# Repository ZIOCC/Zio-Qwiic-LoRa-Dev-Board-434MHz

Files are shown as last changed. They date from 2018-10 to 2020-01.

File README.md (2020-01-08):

# Zio Qwiic LoRa Dev Board 443MHz

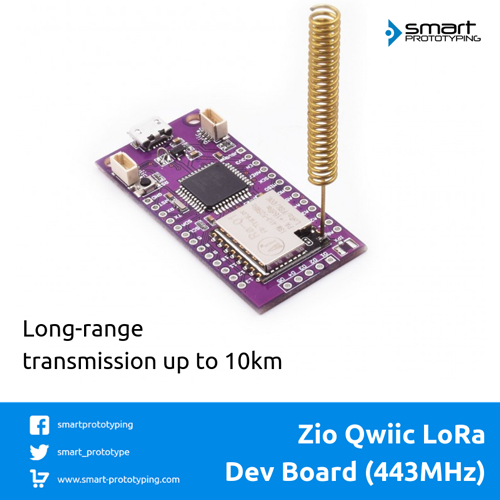
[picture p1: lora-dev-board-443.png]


> This product can be available for purchase [here](https://www.smart-prototyping.com/Zio-Qwiic-LoRa-Dev-Board-443MHz).

#### Description

We know how complicated it is to connect LoRa module, so we make your ‘connecting’ life easier. We created an Arduino IDE compatible board which combines LoRa module + ATMEGA32U4-AU. Simply use two boards, one as a transmitter and another one as a receiver, and the LoRa setup is complete!

There are two Qwiic connectors on board, so you can add more Qwiic modules within seconds without soldering and jumper wire connection. 

The Main IC ATMEGA32U4-AU has almost the same performance as ATmega328, with built-in USB so not only does it have a USB-to-Serial program and debug capability built in with no need for an FTDI-like chip, it can also act like a mouse, keyboard, USB MIDI device, etc.
You can download the driver for ATMEGA32U4-AU [here](https://github.com/adafruit/Adafruit_Windows_Drivers/releases/download/1.2/adafruit_drivers.exe). Alternatively, you can check out the installation guide [here](https://learn.adafruit.com/adafruit-arduino-ide-setup/windows-driver-installation).

The LoRa module on board is based on SX1278 and works on a 433MHz frequency. It can work as master model or slave model. With a spring antenna, the communication distance can reach up to 10 KM in open field. It is a perfect solution for building projects that need to cross a big area. We offer two kinds of LoRa modules on board (optional), the Ra-01 with spring antenna and Ra-02 with IPX antenna. 

The onboard antenna is good enough for you to test function, if you need to implement it for real projects, please solder the antenna to get the best spreading distance.

> If you are looking for the Lora Module instead, you can find it [here](https://www.smart-prototyping.com/index.php?route=product/search&search=lora)

#### Specification

* Program Memory Size (KB): 32
* CPU Speed (MIPS/DMIPS): 16
* SRAM Bytes: 2,560
* Data EEPROM/HEF (bytes): 1024
* Wireless Standard: 433MHz
* Frequency range: 420 - 450MHz

#### Links

* [PCB source file and Gerber file](https://github.com/ZIOCC/Zio-Qwiic-LoRa-Dev-Board-434MHz)
* [Demo code](https://github.com/ZIOCC/Zio-Qwiic-LoRa-Dev-Board-434MHz/tree/master/arduino-LoRa-master)
* [ATMEGA32U4-AU datasheet](http://ww1.microchip.com/downloads/en/DeviceDoc/Atmel-7766-8-bit-AVR-ATmega16U4-32U4_Datasheet.pdf)
* [Arduino IDE Bootloader](https://github.com/adafruit/Adafruit_Windows_Drivers/releases/download/1.2/adafruit_drivers.exe)

###### About Zio
> Zio is a new line of open sourced, compact, and grid layout boards, fully integrated for Arduino and Qwiic ecosystem. Designed ideally for wearables, robotics, small-space limitations or other on the go projects. Check out other awesome Zio products [here](https://www.smart-prototyping.com/Zio).

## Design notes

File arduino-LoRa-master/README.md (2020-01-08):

# Arduino LoRa



An [Arduino](https://arduino.cc/) library for sending and receiving data using [LoRa](https://www.lora-alliance.org/) radios.

## Compatible Hardware

 * [Semtech SX1276/77/78/79](http://www.semtech.com/apps/product.php?pn=SX1276) based boards including:
   * [Dragino Lora Shield](http://www.dragino.com/products/module/item/102-lora-shield.html)
   * [HopeRF](http://www.hoperf.com/rf_transceiver/lora/) [RFM95W](http://www.hoperf.com/rf_transceiver/lora/RFM95W.html), [RFM96W](http://www.hoperf.com/rf_transceiver/lora/RFM96W.html), and [RFM98W](http://www.hoperf.com/rf_transceiver/lora/RFM98W.html)
   * [Modtronix](http://modtronix.com/) [inAir4](http://modtronix.com/inair4.html), [inAir9](http://modtronix.com/inair9.html), and [inAir9B](http://modtronix.com/inair9b.html)
 * [Arduino MKR WAN 1300](https://store.arduino.cc/usa/mkr-wan-1300)
   * **NOTE:** Requires firmware v1.1.6 or later on the on-board Murata module. Please use the [MKRWANFWUpdate_standalone example](https://github.com/arduino-libraries/MKRWAN/blob/master/examples/MKRWANFWUpdate_standalone/MKRWANFWUpdate_standalone.ino) from latest [MKRWAN library](https://github.com/arduino-libraries/MKRWAN) release to update the firmware.
   * **WARNING**: [LoRa.onReceive(...)](https://github.com/sandeepmistry/arduino-LoRa/blob/master/API.md#register-callback) and [LoRa.recieve()](https://github.com/sandeepmistry/arduino-LoRa/blob/master/API.md#receive-mode) is not compatible with this board!

### Semtech SX1276/77/78/79 wiring

| Semtech SX1276/77/78/79 | Arduino |
| :---: | :---:|
| VCC | 3.3V |
| GND | GND |
| SCK | SCK |
| MISO | MISO |
| MOSI | MOSI |
| NSS | 8 |
| NRESET | 4 |
| DIO0 | 7 |

`NSS`, `NRESET`, and `DIO0` pins can be changed by using `LoRa.setPins(ss, reset, dio0)`. `DIO0` pin is optional, it is only needed for receive callback mode. If `DIO0` pin is used, it **must** be interrupt capable via [`attachInterrupt(...)`](https://www.arduino.cc/en/Reference/AttachInterrupt).

**NOTES**:
 * Some boards (like the Arduino Nano), cannot supply enough current for the SX127x in TX mode. This will cause lockups when sending, be sure to use an external 3.3V supply that can provide at least 120mA's when using these boards.
 * If your Arduino board operates at 5V, like the Arduino Uno, Leonardo or Mega, you will need to use a level converter for the wiring to the Semtech SX127x module. Most Semtech SX127x breakout boards do not have logic level converters built-in.

## Installation

### Using the Arduino IDE Library Manager

1. Choose `Sketch` -> `Include Library` -> `Manage Libraries...`
2. Type `LoRa` into the search box.
3. Click the row to select the library.
4. Click the `Install` button to install the library.

### Using Git

```sh
cd ~/Documents/Arduino/libraries/
git clone https://github.com/sandeepmistry/arduino-LoRa LoRa
```

## API

See [API.md](API.md).

## Examples

See [examples](examples) folder.

## FAQ

**1) Initilizating the LoRa radio is failing**

Please check the wiring you are using matches what's listed in [Semtech SX1276/77/78/79 wiring](#semtech-sx1276777879-wiring). You can also use `LoRa.setPins(ss, reset, dio0)` to change the default pins used. Some logic level converters cannot operate at 8 MHz, you can call `LoRa.setSPIFrequency(frequency)` to lower the SPI frequency used by the library. Both API's must be called before `LoRa.begin(...)`.

**2) Can other radios see the packets I'm sending?**

Yes, any LoRa radio that are configured with the same radio parameters and in range can see the packets you send.

**3) Is the data I'm sending encrypted?**

No, all data is sent unencrypted. If want your packet data to be encrypted, you must encrypt it before passing it into this library, followed by decrypting on the receiving end.

**4) How does this library differ from LoRaWAN libraries?**

This library exposes the LoRa radio directly, and allows you to send data to any radios in range with same radio parameters. All data is broadcasted and there is no addressing. LoRaWAN builds on top of LoRA, but adds addressing, encryption, and additional layers. It also requires a LoRaWAN gateway and LoRaWAN network and application server.

**5) Does this library honor duty cycles?**

No, you have to manage it by your self.

**6) Which frequencies can I use?**

You can use [this table](https://www.thethingsnetwork.org/wiki/LoRaWAN/Frequencies/By-Country) to lookup the available frequencies by your country. The selectable frequency also depends on your hardware. You can lookup the data sheet or ask your supplier.

Please also notice the frequency dependent duty cycles for legal reasons!

## License

This libary is [licensed](LICENSE) under the [MIT Licence](https://en.wikipedia.org/wiki/MIT_License).

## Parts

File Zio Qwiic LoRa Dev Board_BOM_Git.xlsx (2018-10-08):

 | BOM quantity |  |  | Zio Qwiic LoRa Dev Board | V 1.0 |  |  |  |  | Harry | 2018.8.31
 | Part Identification |  |  |  |  |  |  |  | Customer Information |  | Quantity
# | Part ID / Reference | Manufacturer | Part / Order Number | Description | Value | Package | THT (y/n) | Pins / Pads | Source/Link/ Datasheet/Note | Source / Target Price | Quantity per BOM
1 | C1, C2 |  |  |  | 10uF ±10% 10V | C0603 | n | 2 |  |  | 2
2 | C3, C4, C5, C6 |  |  |  | 100nF ±10% 50V | C0603 | n | 2 |  |  | 4
3 | D1 |  |  |  | RED | LED-0603 | n | 2 |  |  | 1
4 | IC1 | MICROCHIP | ATMEGA32U4-AU |  | ATMEGA32U4-AU | TQFP44 | n | 44 |  |  | 1
5 | J1 | 韩国韩荣 | U-F-M5DD-Y-L |  | U-F-M5DD-Y-L | MICRO-SMD | n | 5 |  |  | 1
6 | J2, J3 |  |  |  | JST-SH-4P | JST-SH-4P-90 | n | 6 |  |  | 2
7 | J4, J5 |  | NA |  | HEADER-13P-2.54MM | 13P-SCREW-2.54 | y | 13 |  |  | 2
8 | J6 |  | NA |  | 5P-2.54 | 5P-2.54 | y | 5 |  |  | 1
9 | K3 | ALPS | SKRKAEE020 |  | SKRKAEE020 | SKRKAEE020 | n | 2 |  |  | 1
10 | Q1 | muRata | CSTCE8M00G55-R0 |  | 8MHz | RESONATOR-SMD | n | 3 |  |  | 1
11 | R1, R2 | FH | RS-03K22R0FT |  | 22R ±1% | R0603 | n | 2 |  |  | 2
12 | R3, R4 |  |  |  | 100k ±1% | R0603 | n | 2 |  |  | 2
13 | R5 |  |  |  | 10k ±1% | R0603 | n | 2 |  |  | 1
14 | R6 | UniOhm | 0603WAF1501T5E |  | 1.5k ±1% | R0603 | n | 2 |  |  | 1
15 | R7, R8 |  |  |  | 4.7K ±1% | R0603 | n | 2 |  |  | 2
16 | U1 |  |  |  | LORA-01 | LORA-01 | n | 16 |  |  | 1
17 | U2 | DIODES | AP2112K-3.3TRG1 |  | AP2112K-3.3TRG1 | SOT23-5 | n | 5 |  |  | 1
18 | X1 |  | NA |  | uFL | U.FL | n | 3 |  |  | 1

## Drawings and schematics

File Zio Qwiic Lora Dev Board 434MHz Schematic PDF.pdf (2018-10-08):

A

A

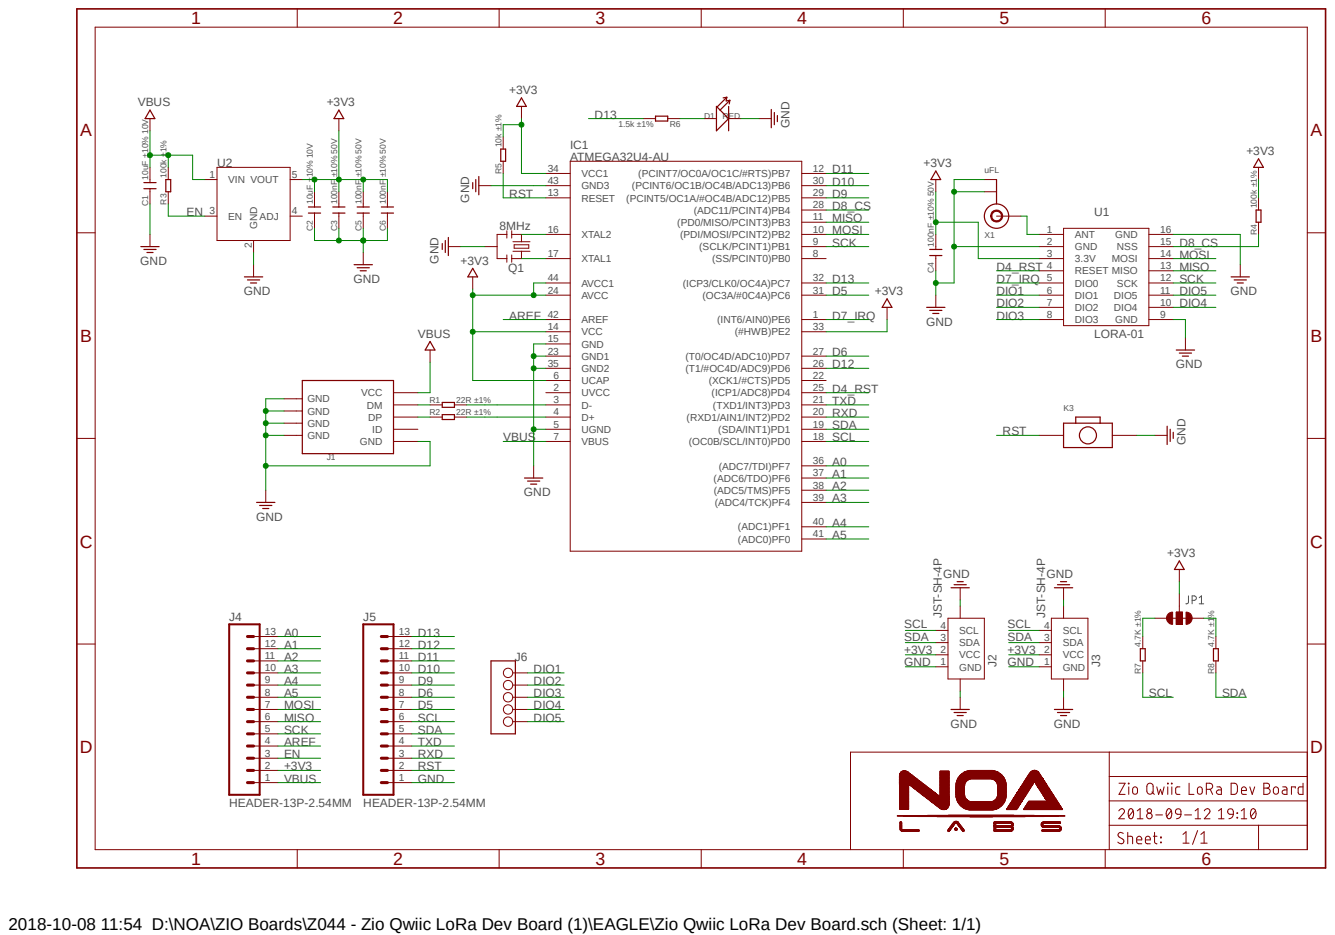
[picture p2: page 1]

2018-10-08 11:54 D:\NOA\ZIO Boards\Z044 - Zio Qwiic LoRa Dev Board (1)\EAGLE\Zio Qwiic LoRa Dev Board.sch (Sheet: 1/1)

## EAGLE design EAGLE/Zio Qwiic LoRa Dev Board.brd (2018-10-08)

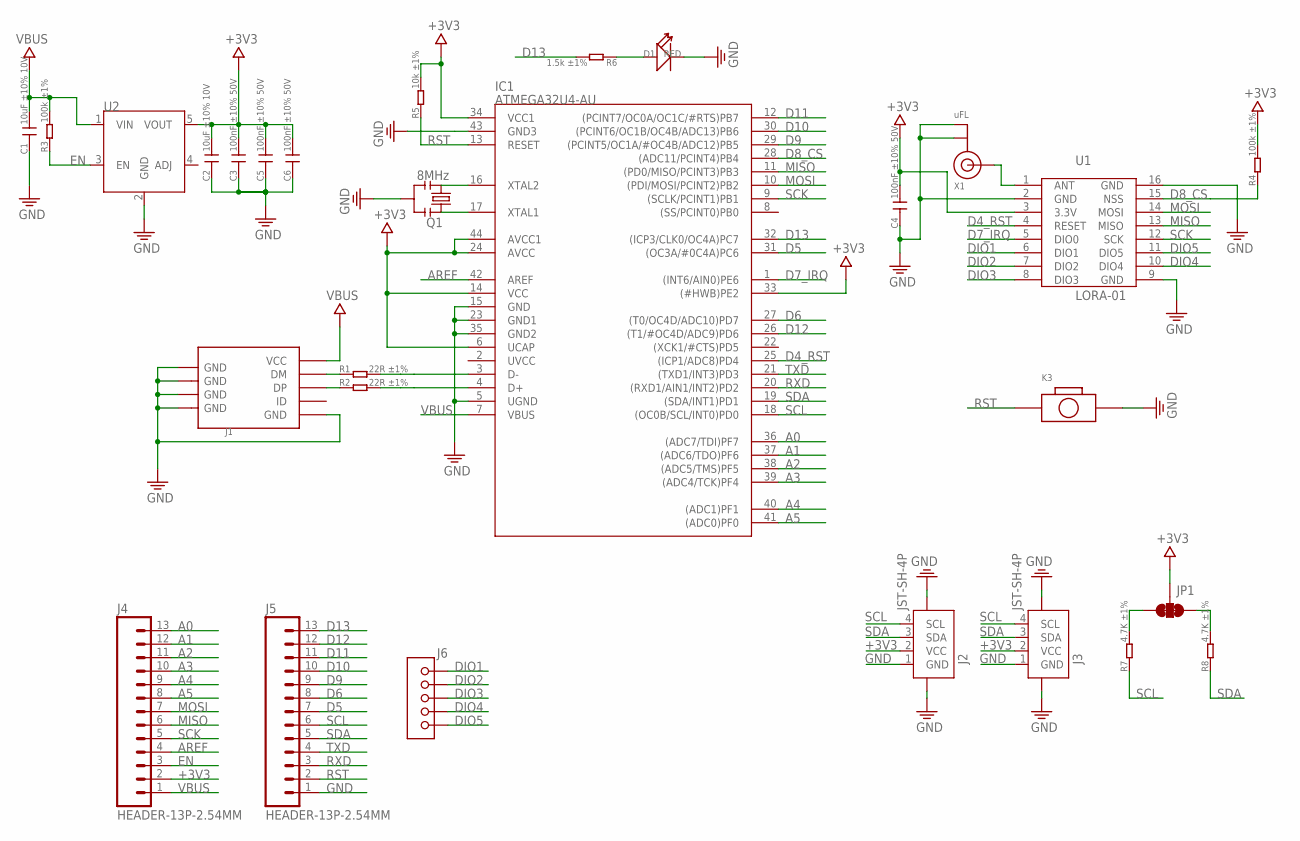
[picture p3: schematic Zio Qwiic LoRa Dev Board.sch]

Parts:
C1, C2: 10uF ±10% 10V; C0603
C3, C4, C5, C6: 100nF ±10% 50V; C0603
D1: RED; LED-0603
IC1: ATMEGA32U4-AU; TQFP44
J1: USB-MICROE; MICRO-SMD
J2, J3: JST-SH-4P; JST-SH-4P-90
J4, J5: HEADER-13P-2.54MM; 13P-SCREW-2.54
J6: HEADER-5P-2.54; 5P-2.54
JP1: SMT-JUMPER_3_2-NC_TRACE
K3: BOTTON-2PSKRKAEE020; SKRKAEE020
Q1: 8MHz; RESONATOR-SMD
R1, R2: 22R ±1%; R0603
R3, R4: 100k ±1%; R0603
R5: 10k ±1%; R0603
R6: 1.5k ±1%; R0603
R7, R8: 4.7K ±1%; R0603
U1: LORA-01
U2: AP2112; SOT23-5
X1: uFL; U.FL

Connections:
+3V3: C2.2, C3.2, C4.2, C5.2, C6.2, IC1.6 (UCAP), IC1.14 (VCC), IC1.24 (AVCC), IC1.33 ((#HWB)PE2), IC1.34 (VCC1), IC1.44 (AVCC1), J2.2 (VCC), J3.2 (VCC), J4.2, JP1.2, R4.2, R5.2, U1.3 (3.3V), U2.5 (VOUT)
A0: IC1.36 ((ADC7/TDI)PF7), J4.13
A1: IC1.37 ((ADC6/TDO)PF6), J4.12
A2: IC1.38 ((ADC5/TMS)PF5), J4.11
A3: IC1.39 ((ADC4/TCK)PF4), J4.10
A4: IC1.40 ((ADC1)PF1), J4.9
A5: IC1.41 ((ADC0)PF0), J4.8
AREF: IC1.42 (AREF), J4.4
D4_RST: IC1.25 ((ICP1/ADC8)PD4), U1.4 (RESET)
D5: IC1.31 ((OC3A/#0C4A)PC6), J5.7
D6: IC1.27 ((T0/OC4D/ADC10)PD7), J5.8
D7_IRQ: IC1.1 ((INT6/AIN0)PE6), U1.5 (DIO0)
D8_CS: IC1.28 ((ADC11/PCINT4)PB4), R4.1, U1.15 (NSS)
D9: IC1.29 ((PCINT5/OC1A/#OC4B/ADC12)PB5), J5.9
D10: IC1.30 ((PCINT6/OC1B/OC4B/ADC13)PB6), J5.10
D11: IC1.12 ((PCINT7/OC0A/OC1C/#RTS)PB7), J5.11
D12: IC1.26 ((T1/#OC4D/ADC9)PD6), J5.12
D13: IC1.32 ((ICP3/CLK0/OC4A)PC7), J5.13, R6.2
DIO1: J6.1, U1.6 (DIO1)
DIO2: J6.2, U1.7 (DIO2)
DIO3: J6.3, U1.8 (DIO3)
DIO4: J6.4, U1.10 (DIO4)
DIO5: J6.5, U1.11 (DIO5)
EN: J4.3, R3.1, U2.3 (EN)
GND: C1.1, C2.1, C3.1, C4.1, C5.1, C6.1, D1.-, IC1.5 (UGND), IC1.15 (GND), IC1.23 (GND1), IC1.35 (GND2), IC1.43 (GND3), J1.GND, J1.S1 (GND), J1.S1@1 (GND), J1.S1@2 (GND), J1.S2 (GND), J1.S2@1 (GND), J1.S2@2 (GND), J1.S3 (GND), J1.S3@1 (GND), J1.S3@2 (GND), J1.S4 (GND), J1.S4@1 (GND), J1.S4@2 (GND), J1.S5 (GND), J1.S6 (GND), J2.1 (GND), J2.5, J2.6, J3.1 (GND), J3.5, J3.6, J5.1, K3.2, Q1.2, U1.2 (GND), U1.9 (GND), U1.16 (GND), U2.2 (GND), X1.1 (GND), X1.2 (GND)
MISO: IC1.11 ((PD0/MISO/PCINT3)PB3), J4.6, U1.13 (MISO)
MOSI: IC1.10 ((PDI/MOSI/PCINT2)PB2), J4.7, U1.14 (MOSI)
unnamed: J1.D- (DM), R1.1
unnamed: J1.D+ (DP), R2.1
unnamed: IC1.4 (D+), R2.2
unnamed: IC1.3 (D-), R1.2
unnamed: IC1.16 (XTAL2), Q1.3
unnamed: D1.+, R6.1
unnamed: IC1.17 (XTAL1), Q1.1
unnamed: U1.1 (ANT), X1.3 (SIGNAL)
unnamed: JP1.3, R7.2
unnamed: JP1.1, R8.2
RST: IC1.13 (RESET), J5.2, K3.1, R5.1
RXD: IC1.20 ((RXD1/AIN1/INT2)PD2), J5.3
SCK: IC1.9 ((SCLK/PCINT1)PB1), J4.5, U1.12 (SCK)
SCL: IC1.18 ((OC0B/SCL/INT0)PD0), J2.4 (SCL), J3.4 (SCL), J5.6, R7.1
SDA: IC1.19 ((SDA/INT1)PD1), J2.3 (SDA), J3.3 (SDA), J5.5, R8.1
TXD: IC1.21 ((TXD1/INT3)PD3), J5.4
VBUS: C1.2, IC1.7 (VBUS), J1.VBUS (VCC), J4.1, R3.2, U2.1 (VIN)

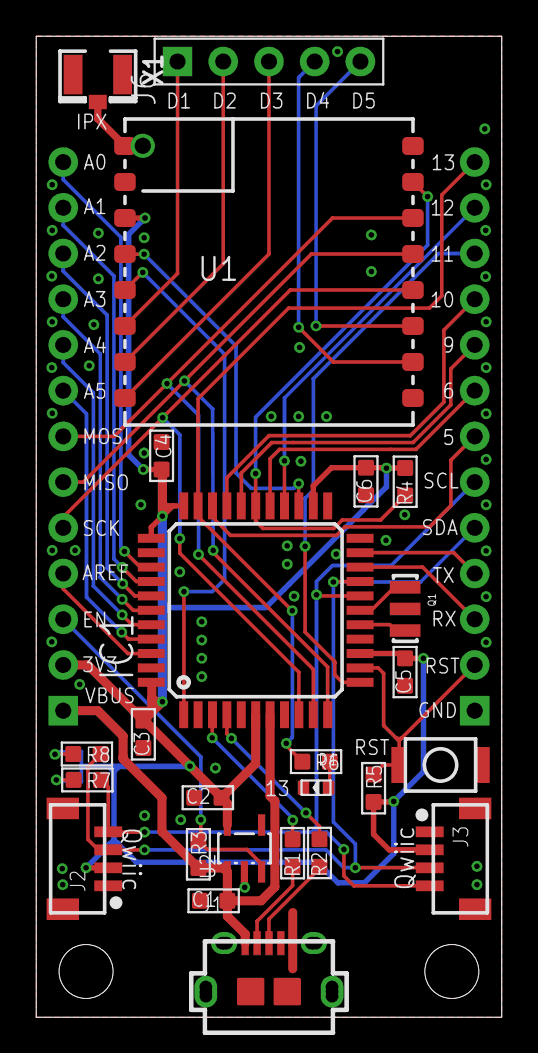
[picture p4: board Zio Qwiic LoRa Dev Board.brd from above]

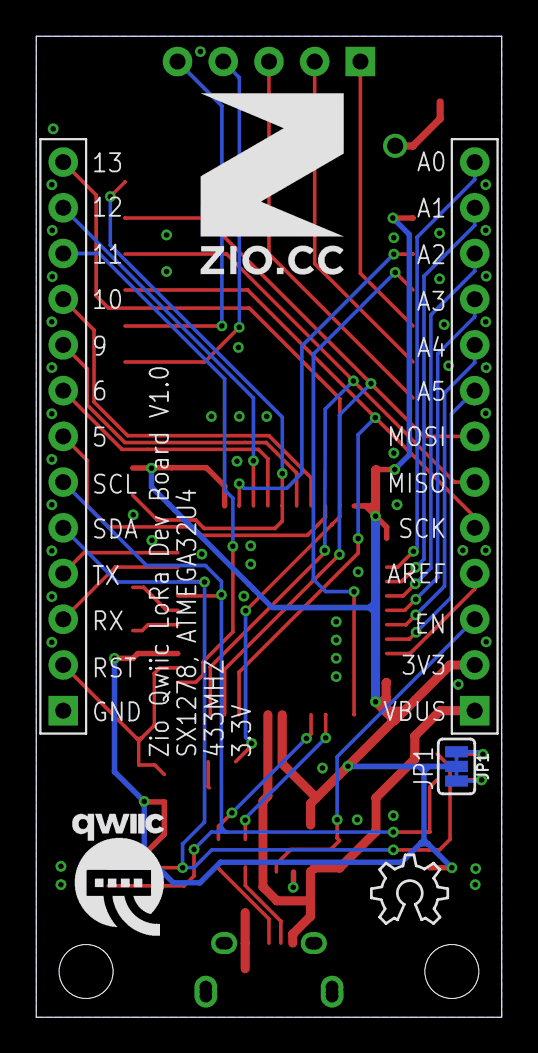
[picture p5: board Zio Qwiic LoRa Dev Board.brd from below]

Board: 2 copper layers, 25.9 x 54.5 mm, 31 parts (6 on the bottom side), 44 nets.

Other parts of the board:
U$10: 10MM
U$11: QWIIC-LOGO-MEDIUM
U$12: OSHW_6X150_NOTEXT

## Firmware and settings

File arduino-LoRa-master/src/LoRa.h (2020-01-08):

// Copyright (c) Sandeep Mistry. All rights reserved.
// Licensed under the MIT license. See LICENSE file in the project root for full license information.

#ifndef LORA_H
#define LORA_H

#include <Arduino.h>
#include <SPI.h>

#ifdef ARDUINO_SAMD_MKRWAN1300
#define LORA_DEFAULT_SPI           SPI1
#define LORA_DEFAULT_SPI_FREQUENCY 250000
#define LORA_DEFAULT_SS_PIN        LORA_IRQ_DUMB
#define LORA_DEFAULT_RESET_PIN     -1
#define LORA_DEFAULT_DIO0_PIN      -1
#else
#define LORA_DEFAULT_SPI           SPI
#define LORA_DEFAULT_SPI_FREQUENCY 8E6 

//Zio Qwiic Lora Dev Board
#define LORA_DEFAULT_SS_PIN        8
#define LORA_DEFAULT_RESET_PIN     4
#define LORA_DEFAULT_DIO0_PIN      7


#endif

#define PA_OUTPUT_RFO_PIN          0
#define PA_OUTPUT_PA_BOOST_PIN     1

class LoRaClass : public Stream {
public:
  LoRaClass();

  int begin(long frequency);
  void end();

  int beginPacket(int implicitHeader = false);
  int endPacket(bool async = false);

  int parsePacket(int size = 0);
  int packetRssi();
  float packetSnr();
  long packetFrequencyError();

  // from Print
  virtual size_t write(uint8_t byte);
  virtual size_t write(const uint8_t *buffer, size_t size);

  // from Stream
  virtual int available();
  virtual int read();
  virtual int peek();
  virtual void flush();

#ifndef ARDUINO_SAMD_MKRWAN1300
  void onReceive(void(*callback)(int));

  void receive(int size = 0);
#endif
  void idle();
  void sleep();

  void setTxPower(int level, int outputPin = PA_OUTPUT_PA_BOOST_PIN);
  void setFrequency(long frequency);
  void setSpreadingFactor(int sf);
  void setSignalBandwidth(long sbw);
  void setCodingRate4(int denominator);
  void setPreambleLength(long length);
  void setSyncWord(int sw);
  void enableCrc();
  void disableCrc();
  void enableInvertIQ();
  void disableInvertIQ();
  
  void setOCP(uint8_t mA); // Over Current Protection control

  // deprecated
  void crc() { enableCrc(); }
  void noCrc() { disableCrc(); }

  byte random();

  void setPins(int ss = LORA_DEFAULT_SS_PIN, int reset = LORA_DEFAULT_RESET_PIN, int dio0 = LORA_DEFAULT_DIO0_PIN);
  void setSPI(SPIClass& spi);
  void setSPIFrequency(uint32_t frequency);

  void dumpRegisters(Stream& out);

private:
  void explicitHeaderMode();
  void implicitHeaderMode();

  void handleDio0Rise();
  bool isTransmitting();

  int getSpreadingFactor();
  long getSignalBandwidth();

  void setLdoFlag();

  uint8_t readRegister(uint8_t address);
  void writeRegister(uint8_t address, uint8_t value);
  uint8_t singleTransfer(uint8_t address, uint8_t value);

  static void onDio0Rise();

private:
  SPISettings _spiSettings;
  SPIClass* _spi;
  int _ss;
  int _reset;
  int _dio0;
  long _frequency;
  int _packetIndex;
  int _implicitHeaderMode;
  void (*_onReceive)(int);
};

extern LoRaClass LoRa;

#endif

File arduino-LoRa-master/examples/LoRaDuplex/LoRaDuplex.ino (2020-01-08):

/*
  LoRa Duplex communication

  Sends a message every half second, and polls continually
  for new incoming messages. Implements a one-byte addressing scheme,
  with 0xFF as the broadcast address.

  Uses readString() from Stream class to read payload. The Stream class'
  timeout may affect other functuons, like the radio's callback. For an

  created 28 April 2017
  by Tom Igoe
*/
#include <SPI.h>              // include libraries
#include <LoRa.h>

const int csPin = 7;          // LoRa radio chip select
const int resetPin = 6;       // LoRa radio reset
const int irqPin = 1;         // change for your board; must be a hardware interrupt pin

String outgoing;              // outgoing message

byte msgCount = 0;            // count of outgoing messages
byte localAddress = 0xBB;     // address of this device
byte destination = 0xFF;      // destination to send to
long lastSendTime = 0;        // last send time
int interval = 2000;          // interval between sends

void setup() {
  Serial.begin(9600);                   // initialize serial
  while (!Serial);

  Serial.println("LoRa Duplex");

  // override the default CS, reset, and IRQ pins (optional)
  LoRa.setPins(csPin, resetPin, irqPin);// set CS, reset, IRQ pin

  if (!LoRa.begin(433E6)) {             // initialize ratio at 915 MHz
    Serial.println("LoRa init failed. Check your connections.");
    while (true);                       // if failed, do nothing
  }

  Serial.println("LoRa init succeeded.");
}

void loop() {
  if (millis() - lastSendTime > interval) {
    String message = "HeLoRa World!";   // send a message
    sendMessage(message);
    Serial.println("Sending " + message);
    lastSendTime = millis();            // timestamp the message
    interval = random(2000) + 1000;    // 2-3 seconds
  }

  // parse for a packet, and call onReceive with the result:
  onReceive(LoRa.parsePacket());
}

void sendMessage(String outgoing) {
  LoRa.beginPacket();                   // start packet
  LoRa.write(destination);              // add destination address
  LoRa.write(localAddress);             // add sender address
  LoRa.write(msgCount);                 // add message ID
  LoRa.write(outgoing.length());        // add payload length
  LoRa.print(outgoing);                 // add payload
  LoRa.endPacket();                     // finish packet and send it
  msgCount++;                           // increment message ID
}

void onReceive(int packetSize) {
  if (packetSize == 0) return;          // if there's no packet, return

  // read packet header bytes:
  int recipient = LoRa.read();          // recipient address
  byte sender = LoRa.read();            // sender address
  byte incomingMsgId = LoRa.read();     // incoming msg ID
  byte incomingLength = LoRa.read();    // incoming msg length

  String incoming = "";

  while (LoRa.available()) {
    incoming += (char)LoRa.read();
  }

  if (incomingLength != incoming.length()) {   // check length for error
    Serial.println("error: message length does not match length");
    return;                             // skip rest of function
  }

  // if the recipient isn't this device or broadcast,
  if (recipient != localAddress && recipient != 0xFF) {
    Serial.println("This message is not for me.");
    return;                             // skip rest of function
  }

  // if message is for this device, or broadcast, print details:
  Serial.println("Received from: 0x" + String(sender, HEX));
  Serial.println("Sent to: 0x" + String(recipient, HEX));
  Serial.println("Message ID: " + String(incomingMsgId));
  Serial.println("Message length: " + String(incomingLength));
  Serial.println("Message: " + incoming);
  Serial.println("RSSI: " + String(LoRa.packetRssi()));
  Serial.println("Snr: " + String(LoRa.packetSnr()));
  Serial.println();
}

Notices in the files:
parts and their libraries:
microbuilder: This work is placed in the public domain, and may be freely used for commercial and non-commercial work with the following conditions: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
